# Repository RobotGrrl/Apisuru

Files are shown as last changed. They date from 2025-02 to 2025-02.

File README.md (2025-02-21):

# Apisuru

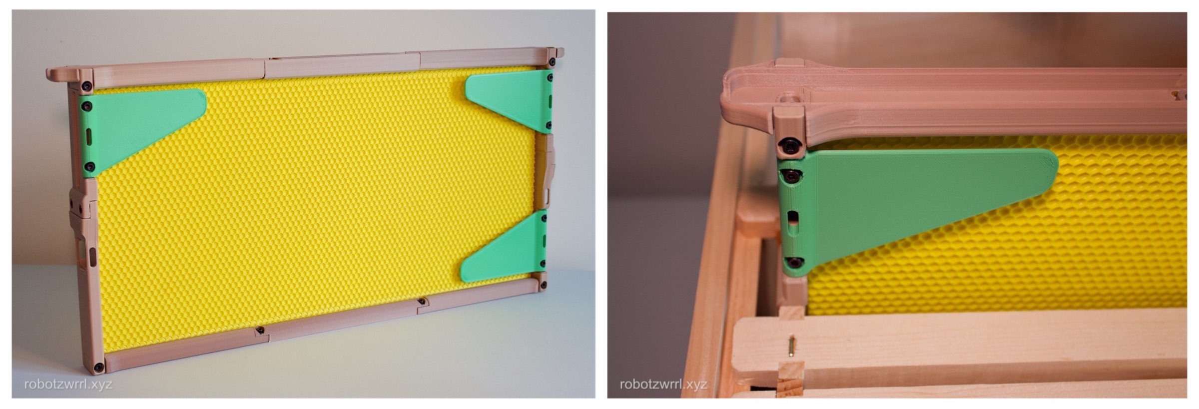
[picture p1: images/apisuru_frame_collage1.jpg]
Apisuru Frame Photographs


**Apisuru** is a bee frame design featuring sensor panels and pockets for electronics that is designed for 3D printing. Apisuru's deep [frame dimensions](https://github.com/RobotGrrl/Apisuru/blob/main/Apisuru_Frame_Dimensional_Drawing.pdf) are based on the widely used [Langstroth Hive](https://beeprofessor.com/langstroth-hive-dimensions/). Foundation can be installed inside the frame by sliding it between the rails in the upper and lower bars.

By integrating sensors, Apisuru could provide remote monitoring of real-time data on pressure, temperature, humidity, sound, and light levels. Tracking these parameters could help identify patterns related to hive health, such as pest invasions or environmental stressors.

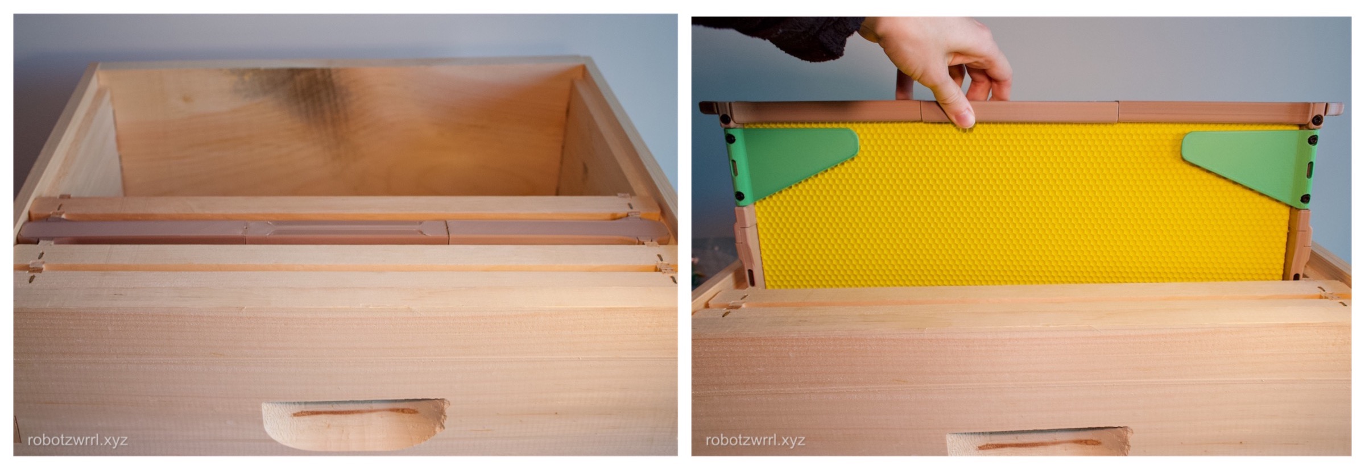
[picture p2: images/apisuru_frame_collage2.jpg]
Apisuru Frame in Bee Box Photographs


Presently, existing frames do not have the space for electronics, such as pockets or channels for wires to pass through. Adding electronics to the outside of existing frames increases the chances of being frozen in place with propolis.

To keep the sensors and electronics clear of the brood area, the sensor panels are placed near the outer arc of the rainbow pattern. The sensor plates are barebones, intended to be modified with whatever your custom sensor plan will be. 

_Note:_ This first iteration of Apisuru might not have the weight holding capability as regular frames, since the piece is split into thirds for 3D printing on smaller build platforms. Improvements are planned for a derivative from the first iteration.

## Sensor Panels

The sensor panels are seen above as the pastel green triangular pieces. Each location with a sensor panel available has the naming convention of `FxBy`, where x and y could be 0 or 1. 0 represents that the piece has the mounting points for a sensor panel. 1 represents that the piece is filled. 

Sensor panels are located on:
- Side upper (left and right)
- Side lower (left and right)
- Lower bar middle
- Upper bar middle

## Dimensional Drawings

Apisuru's deep [frame dimensions](https://github.com/RobotGrrl/Apisuru/blob/main/Apisuru_Frame_Dimensional_Drawing.pdf) are based on the widely used [Langstroth Hive](https://beeprofessor.com/langstroth-hive-dimensions/), as measured with a Dancing Bee Equipment frame for reference.

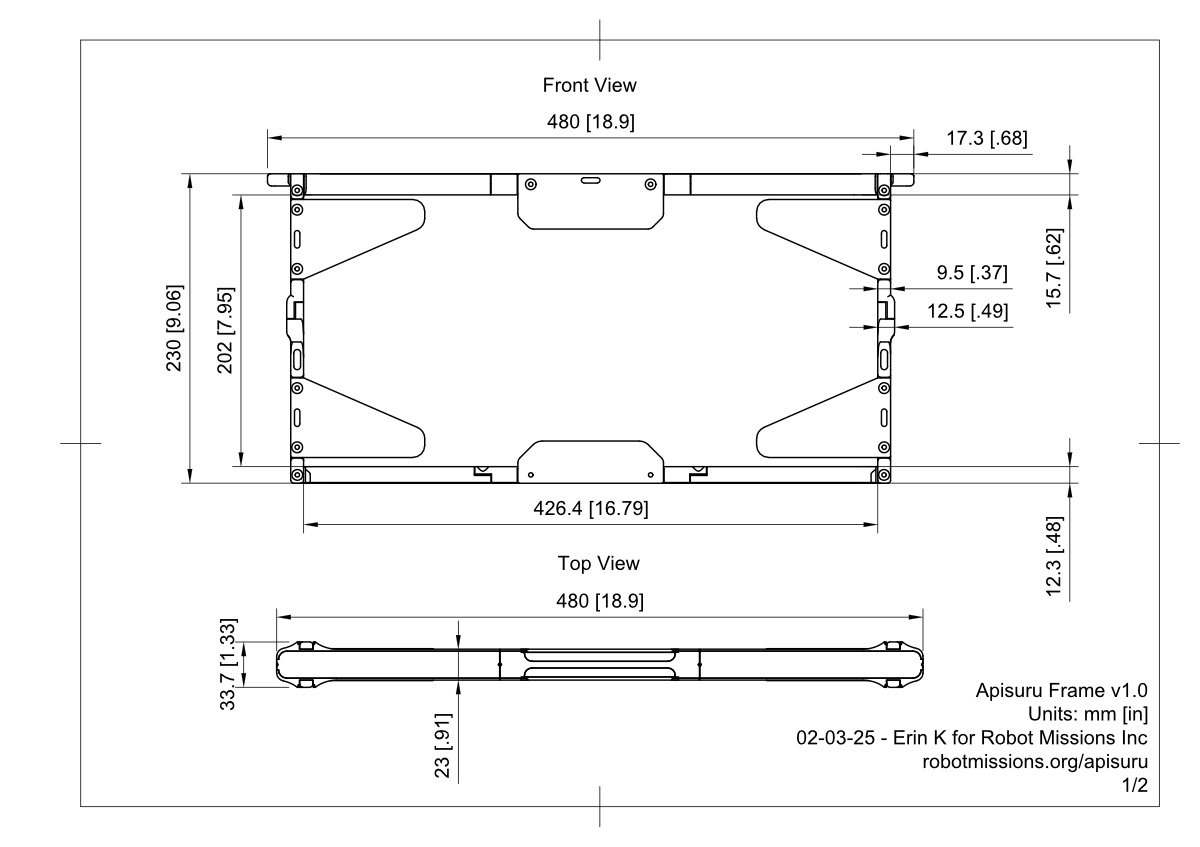
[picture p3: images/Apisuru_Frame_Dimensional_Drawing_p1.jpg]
Apisuru Frame Dimensional Drawing Page 1


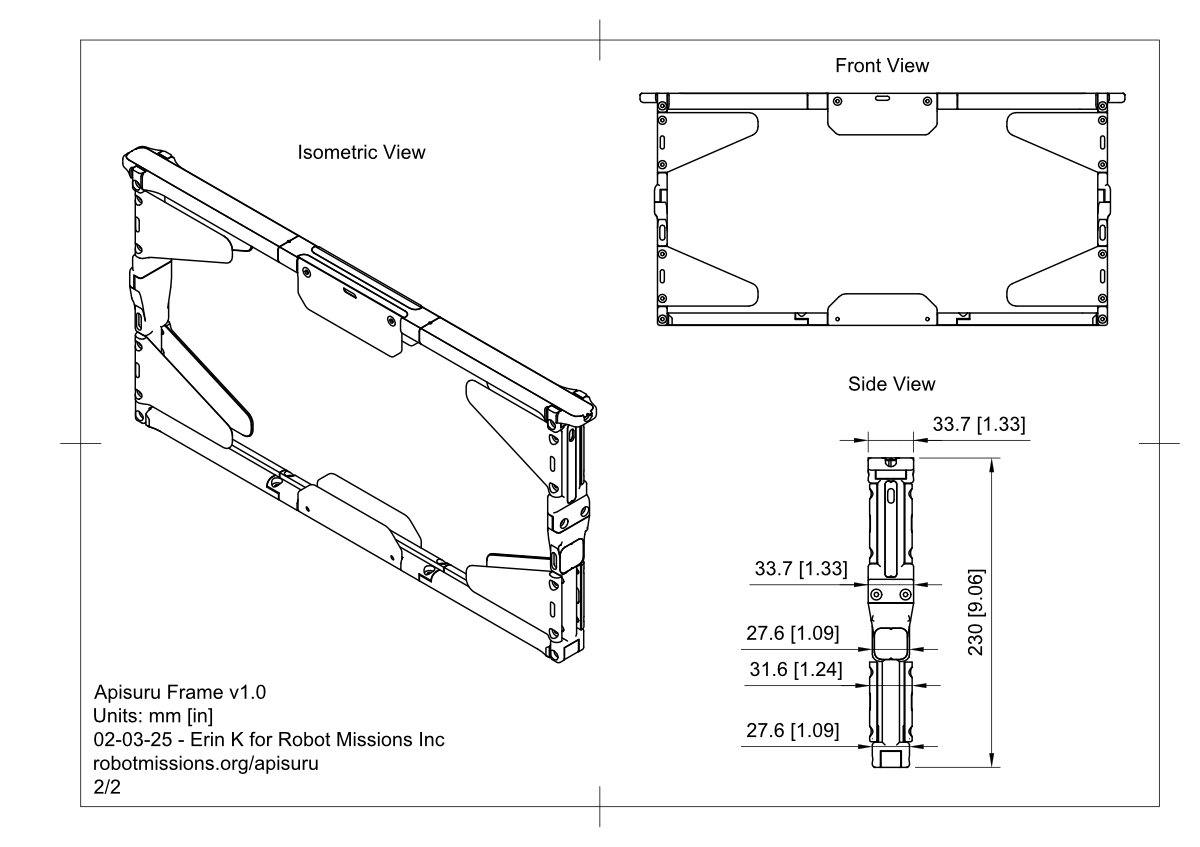
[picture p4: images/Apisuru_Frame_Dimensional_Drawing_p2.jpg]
Apisuru Frame Dimensional Drawing Page 2


## Bill of Materials (BOM)

### Mechanical Components BOM

Each item on the BOM requires the following three mechanical components:

| Component | McMaster-Carr Part Number | Unit Cost (USD) |
| --- | --- | --- |
| M3 Heat-set Insert | 94180A331 | 0.2044 |
| M3 Washer | 98269A420 | 0.0247 |
| M3 Fastener 5 mm | 91290A012 | 0.1810 |
| TOTAL |  | 0.4101 |

### Apisuru BOM

Here is how many of the mechanical components are needed. This is the basic setup, with no sensor plates. Each sensor plate requires qty 2 of the mechanical components set.

| Location | Quantity |
| --- | --- |
| Side Left | 2 |
| Lower | 8 |
| Side Right | 2 |
| Upper | 6 |
| TOTAL | 18 |
| Mechanical Cost | 7.38 |
| |  |
| _For each sensor plate addition_ | _2_ |

## License

**Apisuru** is open source and available under the [CERN Open Hardware license](https://cern-ohl.web.cern.ch/), specifically CERN-OHL-P version 2.0. Let us know if you are interested in adapting Apisuru for an experiment in your hive this bee season!

Apisuru documentation is available under the [CC-BY-4.0 license](https://creativecommons.org/licenses/by/4.0/).

Apisuru © Copyright Erin RobotZwrrl, Robot Missions Inc.

13 Feb 2025 (02-13-25) v1.0

[RobotMissions.org](https://robotmissions.org)

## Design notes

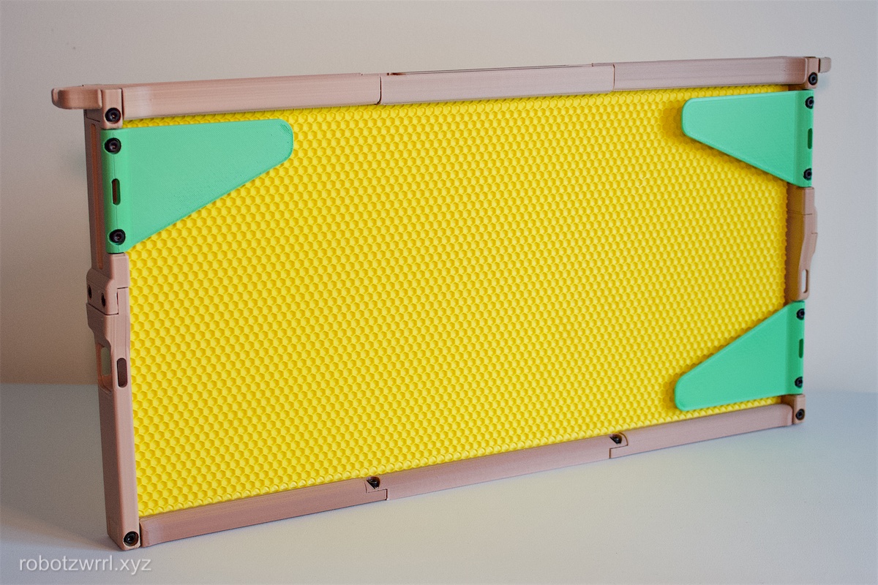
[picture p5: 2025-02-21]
images/apisuru_frame-02.JPG

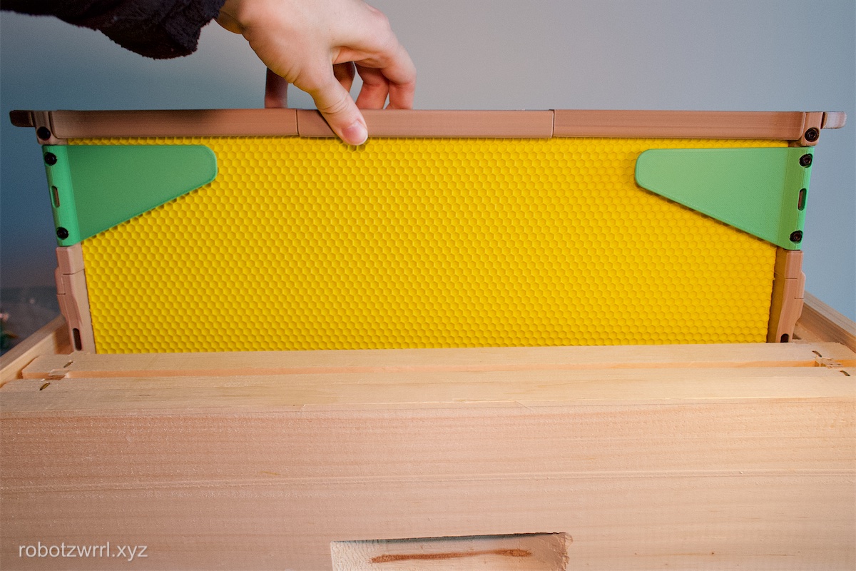
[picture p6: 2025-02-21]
images/apisuru_frame-09.JPG

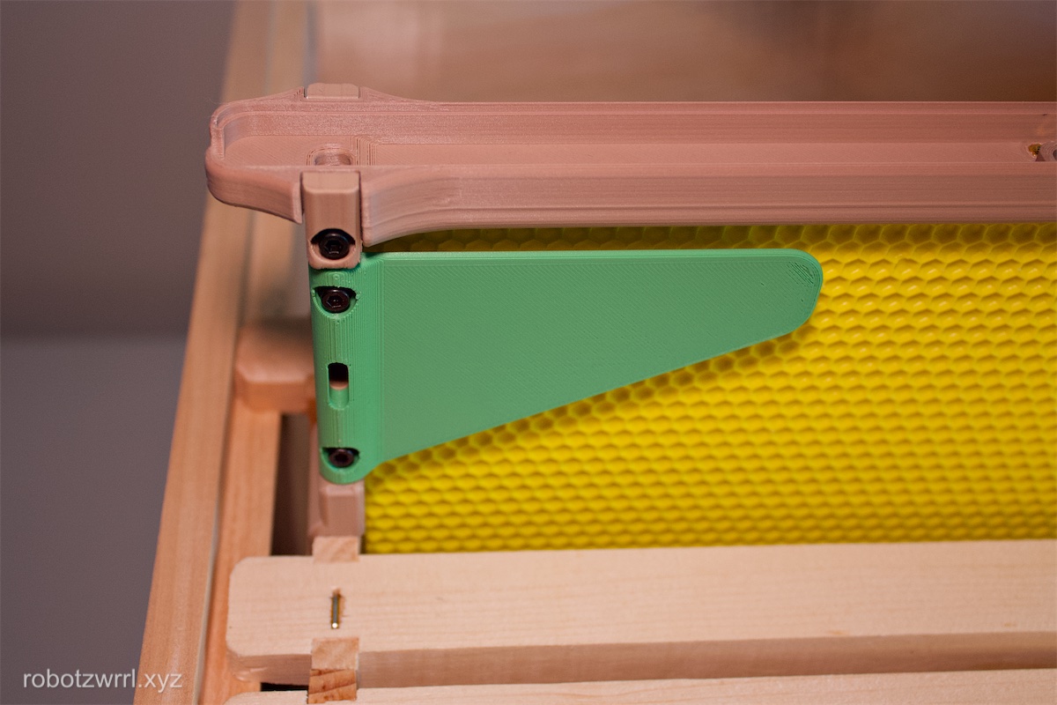
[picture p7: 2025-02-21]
images/apisuru_frame-12.JPG

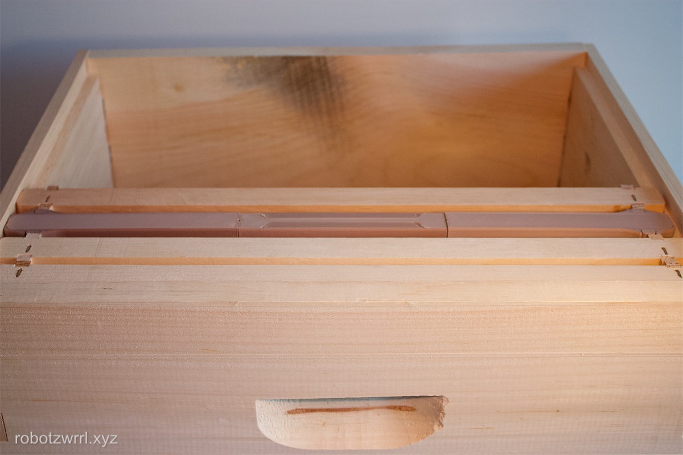
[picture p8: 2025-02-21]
images/apisuru_frame-06.JPG

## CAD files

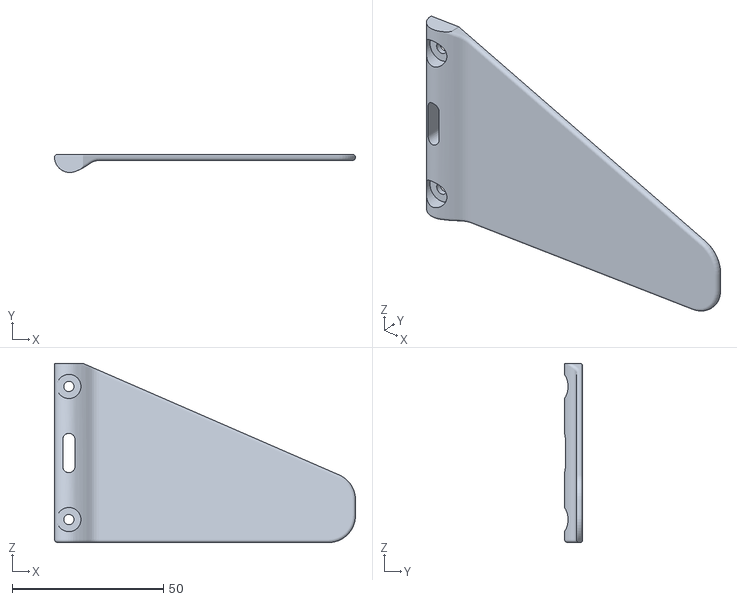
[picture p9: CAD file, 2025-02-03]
3dprint/sensor_plate_lower_left_front.stl
99.5 x 5.95 x 59.2

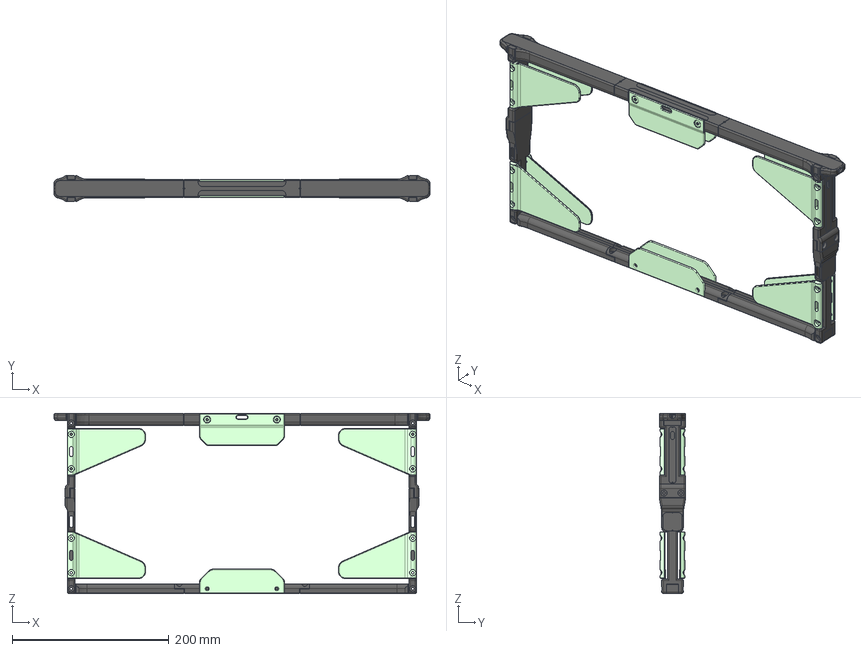
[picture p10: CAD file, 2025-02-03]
cad/Apisuru_Frame.step
480.0 x 33.7 x 230.0 mm
upper bar
lower bar
side
side sensor plate
side lid lower
side lid upper
upper lid mid
upper lid side
side sensor plate(Mirror)
side sensor plate(Mirror) (1)
side sensor plate(Mirror)(Mirror)
side sensor plate(Mirror) (2)
side sensor plate(Mirror)(Mirror) (1)
side sensor plate(Mirror) (1)(Mirror)
side sensor plate(Mirror)(Mirror)(Mirror)
side lid lower(Mirror)
side lid upper(Mirror)
upper lid side(Mirror)
side(Mirror) (2)
upper middle plate
upper middle plate(Mirror)
lower middle plate
lower middle plate(Mirror)

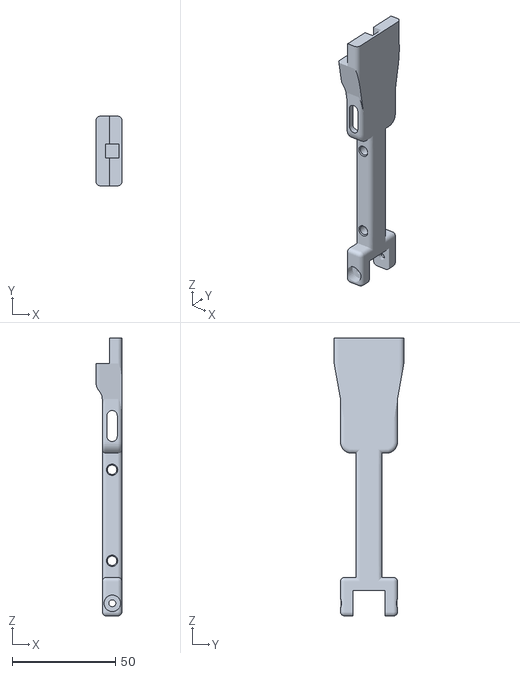
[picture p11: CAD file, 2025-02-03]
3dprint/side_lower_left_F0B0.stl
12.5 x 33.7 x 134.4

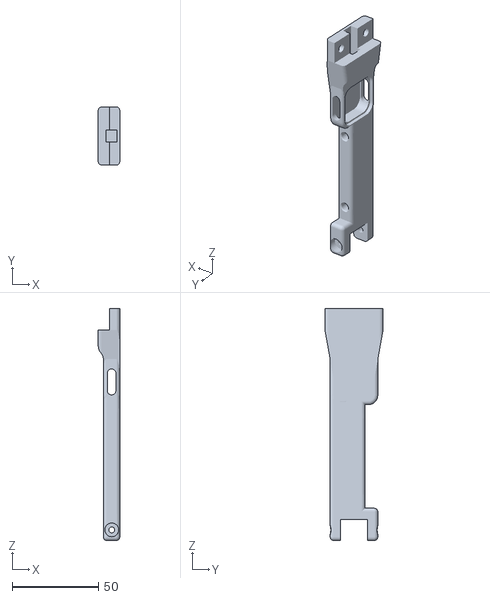
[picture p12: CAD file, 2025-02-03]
3dprint/side_lower_left_F1B0.stl
12.5 x 33.7 x 134.4

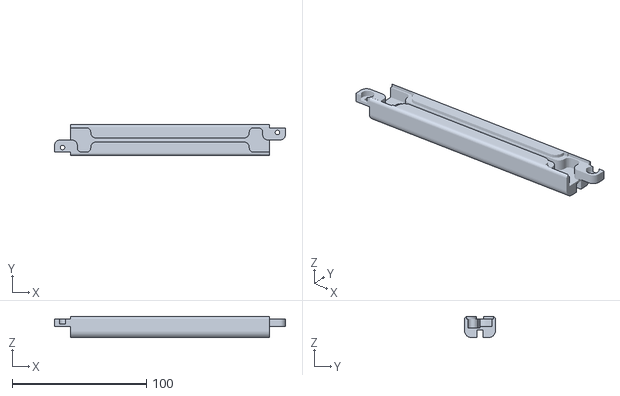
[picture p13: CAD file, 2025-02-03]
3dprint/upper_bar_middle_F1B1.stl
172.0 x 23.0 x 15.7

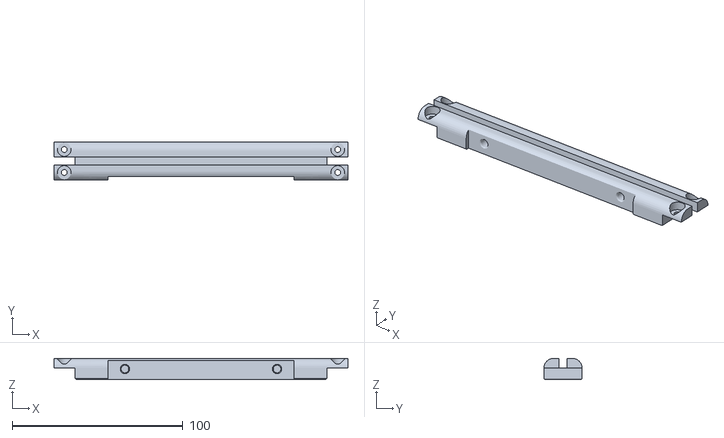
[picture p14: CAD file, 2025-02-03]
3dprint/lower_bar_middle_F0B1.stl
172.0 x 22.3 x 12.3

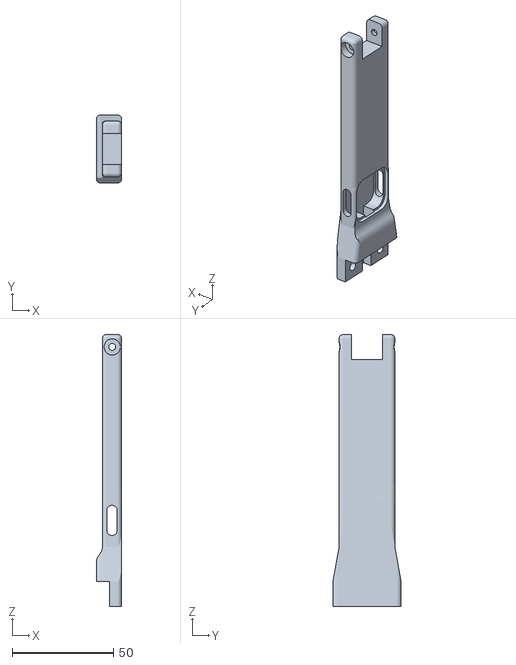
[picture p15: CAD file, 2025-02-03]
3dprint/side_lower_right_F1B1.stl
12.5 x 33.7 x 134.4

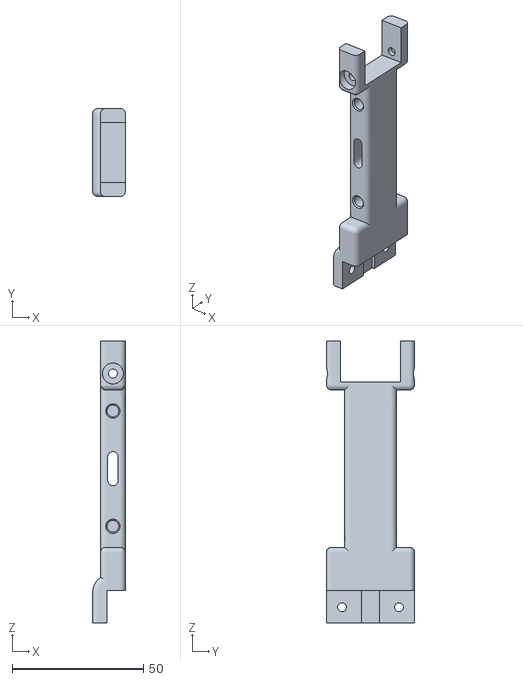
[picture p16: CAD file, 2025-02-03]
3dprint/side_upper_left_F0B0.stl
12.5 x 33.7 x 107.6

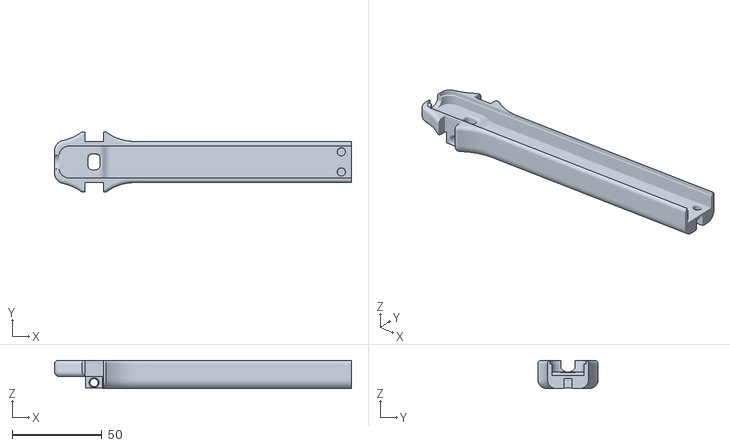
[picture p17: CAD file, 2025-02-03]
3dprint/upper_bar_left.stl
165.6 x 33.7 x 15.7

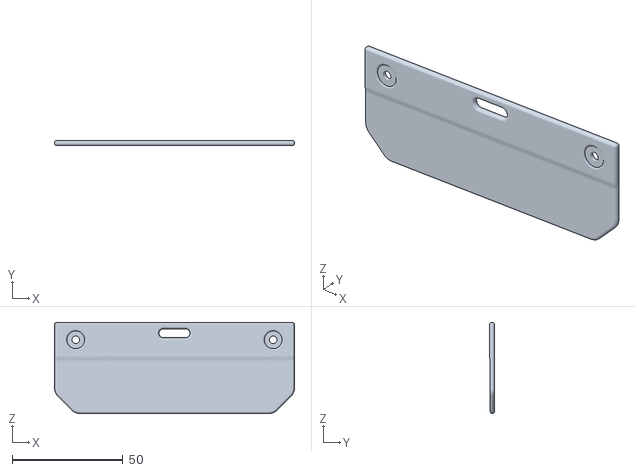
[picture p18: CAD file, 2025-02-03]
3dprint/middle_plate_upper_front.stl
108.2 x 2.40 x 41.1

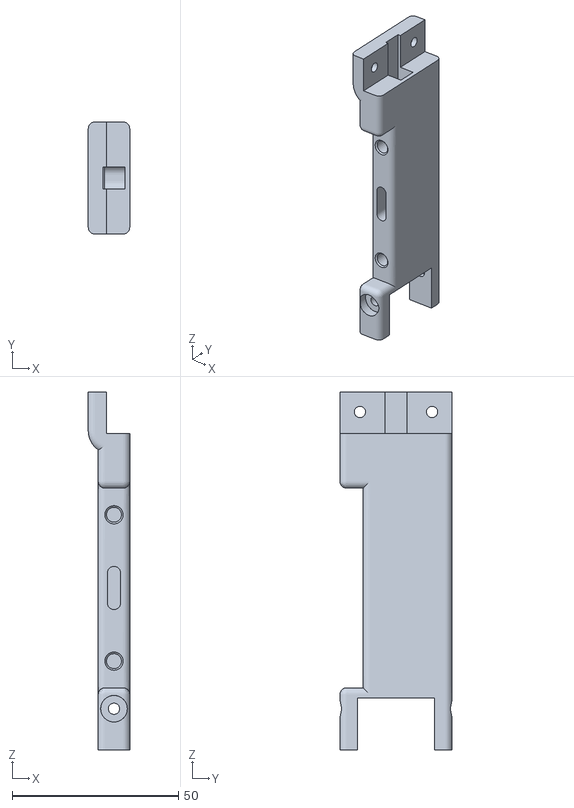
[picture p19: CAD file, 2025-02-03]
3dprint/side_upper_right_F0B1.stl
12.5 x 33.7 x 107.6

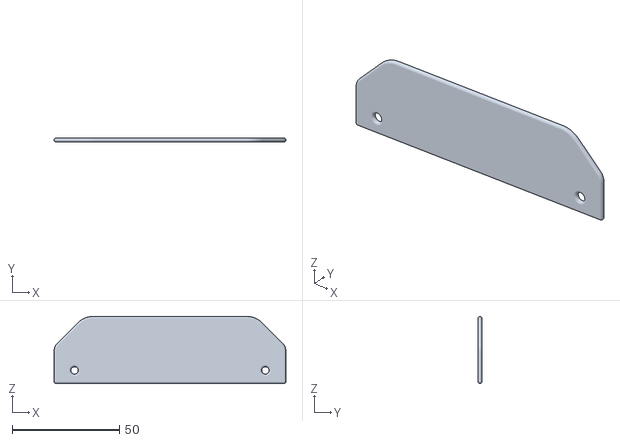
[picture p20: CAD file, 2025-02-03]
3dprint/middle_plate_lower_front.stl
108.2 x 2.00 x 31.4

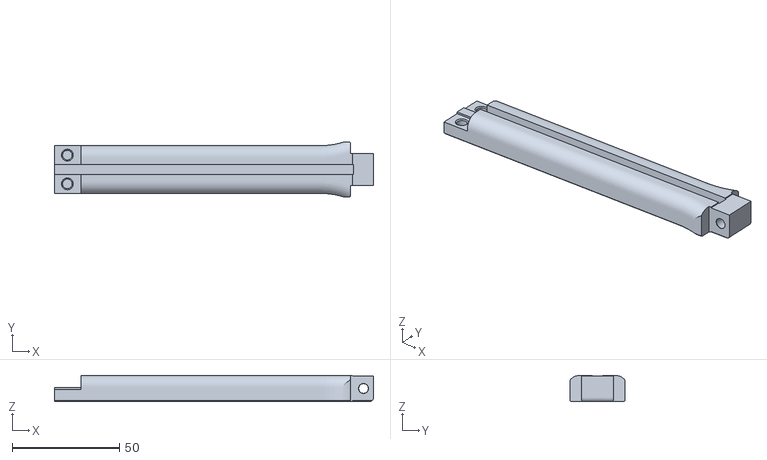
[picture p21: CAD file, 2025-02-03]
3dprint/lower_bar_right.stl
148.5 x 25.6 x 12.3

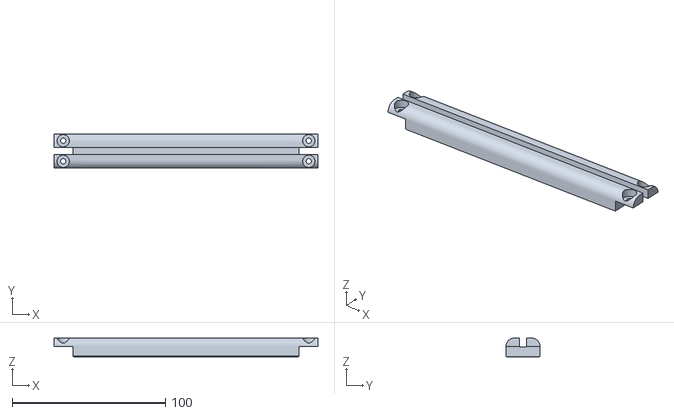
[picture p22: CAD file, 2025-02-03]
3dprint/lower_bar_middle_F1B1.stl
172.0 x 22.3 x 12.3

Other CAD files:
3dprint/side_lower_right_F0B0.stl
3dprint/sensor_plate_lower_left_back.stl
3dprint/sensor_plate_upper_right_back.stl
3dprint/lower_bar_left.stl
3dprint/lower_bar_middle_F0B0.stl
3dprint/lower_bar_middle_F1B0.stl
3dprint/middle_plate_lower_back.stl
3dprint/middle_plate_upper_back.stl
3dprint/sensor_plate_lower_right_front.stl
3dprint/sensor_plate_upper_left_front.stl
3dprint/side_lid_lower_left.stl
3dprint/side_lid_lower_right.stl
3dprint/side_lid_upper_left.stl
3dprint/side_lid_upper_right.stl
3dprint/side_lower_left_F0B1.stl
3dprint/side_lower_left_F1B1.stl
3dprint/side_lower_right_F0B1.stl
3dprint/side_lower_right_F1B0.stl
3dprint/side_upper_left_F0B1.stl
3dprint/side_upper_left_F1B0.stl
3dprint/side_upper_left_F1B1.stl
3dprint/side_upper_right_F0B0.stl
3dprint/side_upper_right_F1B0.stl
3dprint/side_upper_right_F1B1.stl
3dprint/upper_bar_middle_F0B0.stl
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

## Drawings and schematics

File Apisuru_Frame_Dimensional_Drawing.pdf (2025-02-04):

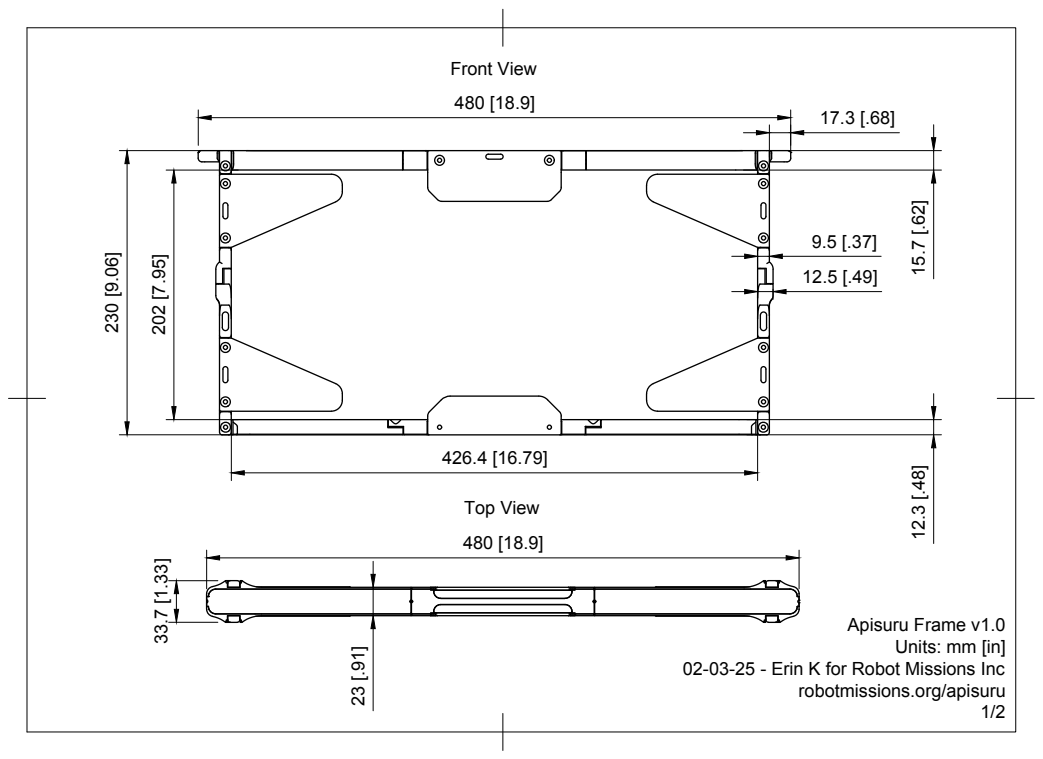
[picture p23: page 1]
Front View; Top View

Apisuru Frame v1.0
Units: mm [in]

02-03-25 - Erin K for Robot Missions Inc

robotmissions.org/apisuru

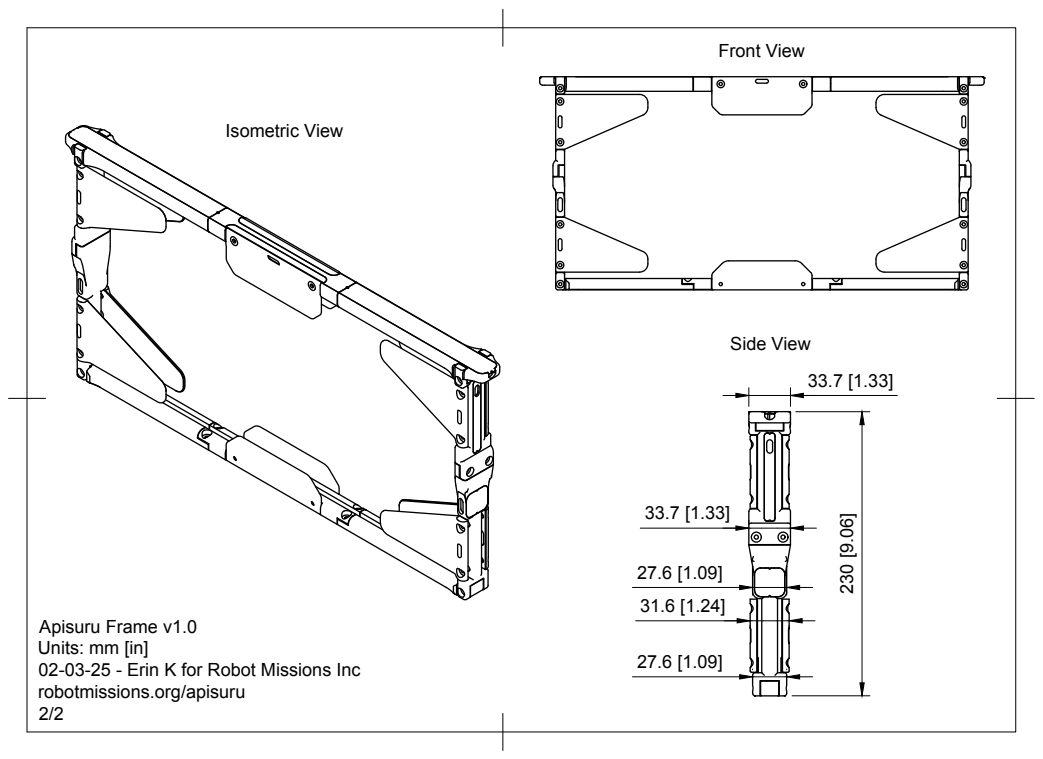
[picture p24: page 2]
Isometric View; Side View; Front View

Apisuru Frame v1.0
Units: mm [in]
02-03-25 - Erin K for Robot Missions Inc
robotmissions.org/apisuru

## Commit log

2025-01-28 Hello world
    [apisuru_frame.f3d, apisuru_frame.step]
2025-02-03 All of the combinations of pieces
    [apisuru_frame.f3d, apisuru_frame.step, lower_bar_left.stl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]
2025-02-04 Add internal frame dimensions
2025-02-18 Change from 8mm fastener to 5mm
